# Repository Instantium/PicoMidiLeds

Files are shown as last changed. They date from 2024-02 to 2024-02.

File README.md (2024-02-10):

# PicoMidiLeds

Use a Pi Pico to control RGB Led strips via midi signals. 

## Features
- Control up to 6 Led channels with midi signals
- Daisy chain controllers together
- Note velocity controls Led brightness
- Dim all Led channels with the modulation control command
- Ignores note_off events so that the leds stay on when the midi track ends
- Set a default value for each channel
- Midi-in and midi-out via DIN-5
- Midi-in via usb
- Optocoupler protects pico from midi-in

## Rationale 

The band [Fliegende Haie](https://fliegendehaie.com) approached me to find a way to control multiple Led strips in accordance to their music tracks on stage.

They already had DIYed stage lighting consisting of two sharks in clouds. 
Each shark consists of two RGB-LED strips (one for the shark and one for the cloud).

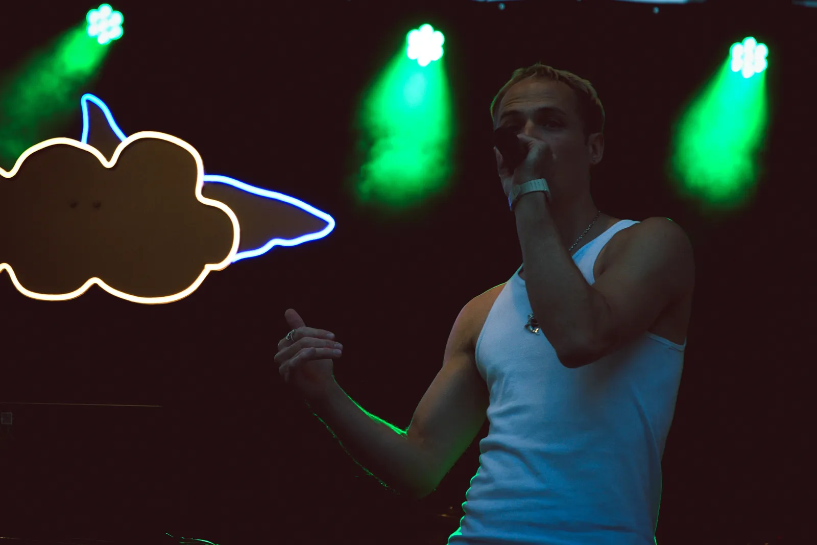
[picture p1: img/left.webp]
[](https://fliegendehaie.com/uber)
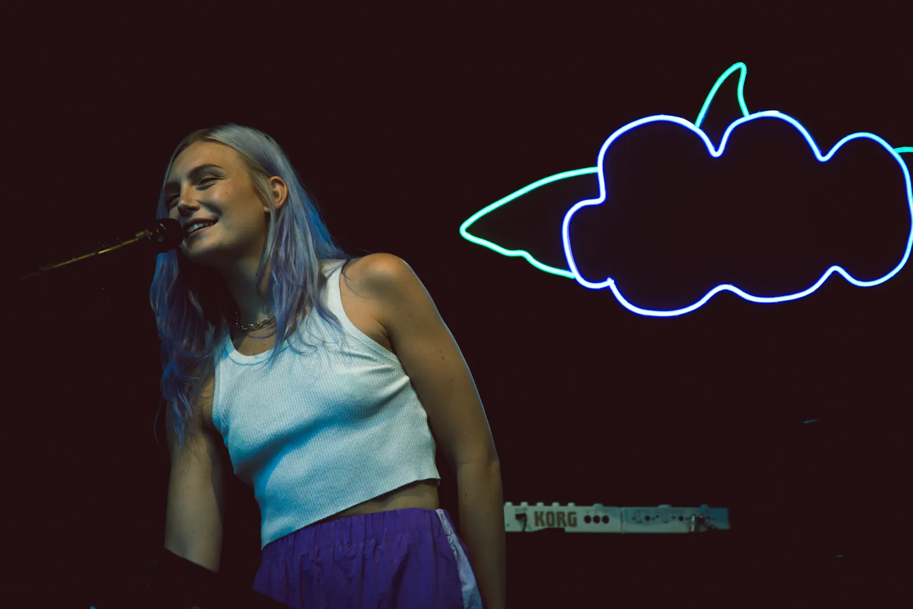
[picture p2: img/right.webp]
[](https://fliegendehaie.com/uber)

Using existing stage lighting solutions (like [DMX](https://en.wikipedia.org/wiki/DMX512)) would mean a huge cost and steep learning curve. 
Since the band members already knew how to write midi tracks and had the hardware, it was the obvious choice to control the lighting via midi commands.



## Setup

### Firmware

- Install [Adafruit cricuit python](https://learn.adafruit.com/getting-started-with-raspberry-pi-pico-circuitpython/circuitpython) on the pico
- Download [library bundle](https://circuitpython.org/libraries)
- Copy adafruit midi to the Pico
- Rename PicoMidi.py to code.py
- Copy config.py and code.py to the Pico

### Config

Configurations should be made in the config.py file. See comments for explanation.

### PCB 

You can use the [Kicad project](board/pico-midi-leds/pico-midi-leds.kicad_pro) or just send the production files (board/pico-midi-leds/production/pico-midi-leds_2024-02-07_08-46-34) to a PCB-Manufacturerer. Or approach me since I have some populated boards left over.

Version 1 with bodgewires (already fixed):

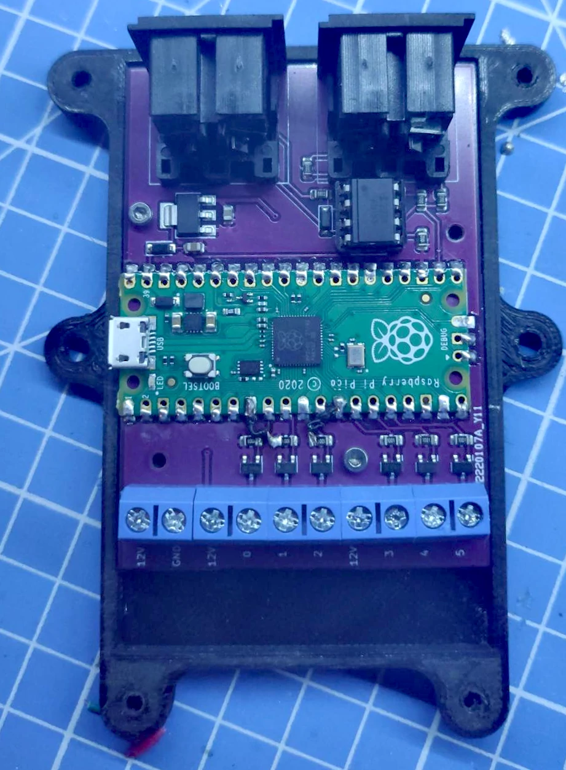
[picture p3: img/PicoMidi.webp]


### Enclosure

I added the stl files for an enclosure [Top](enclosure/PicoMidi%20-%20Lid.stl) and [Bottom](enclosure/PicoMidi%20-%20Bottom.stl) that can be used as enclosure.

## Todos
- Specify midi channel
- Enable midi out from usb (reqiures hardware change)
- Make ignoring note_off configurable

## Thanks

Thanks to [Fliegende Haie](https://fliegendehaie.com) for agreeing to make this project open source.

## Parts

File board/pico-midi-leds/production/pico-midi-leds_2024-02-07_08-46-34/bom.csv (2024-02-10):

Designator | Footprint | Quantity | Value | LCSC Part #
C1 | 0805 | 1 | 10u
C2 | 0805 | 1 | 22u
D1 | D_SOD-123 | 1 | 1N4148
D2 | D_SOD-123 | 1 | D_Schottky
H1, H2, H3, H4 | MountingHole_2.2mm_M2 | 4 | MountingHole
J1, J2 | TerminalBlock_bornier-4_P5.08mm | 2 | Screw_Terminal_01x04
J3 | TerminalBlock_bornier-2_P5.08mm | 1 | Screw_Terminal_01x02
J4, J5 | din-504-M10 | 2 | DIN-5_180degree | C2939344
Q1, Q2, Q3, Q4, Q5, Q6 | SOT-23 | 6 | IRLZ44N
R1, R4, R5 | 0805 | 3 | 220R
R10, R11, R6, R7, R8, R9 | 0805 | 6 | 1k
R2 | 0805 | 1 | 470R
R3 | 0805 | 1 | 10kR
U1 | RPi_Pico_SMD_TH | 1 | Pico
U2 | DIP-8_W7.62mm | 1 | 6N138
U3 | SOT-223-3_TabPin2 | 1 | AMS1117-5.0

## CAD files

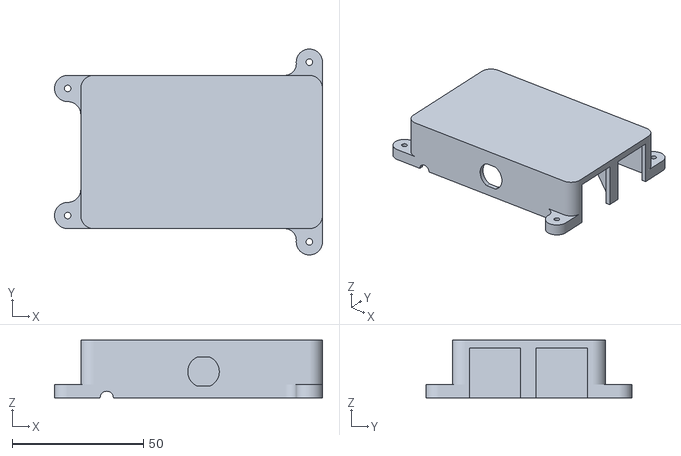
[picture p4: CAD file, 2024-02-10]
enclosure/PicoMidi - Lid.stl
102.0 x 78.3 x 21.9

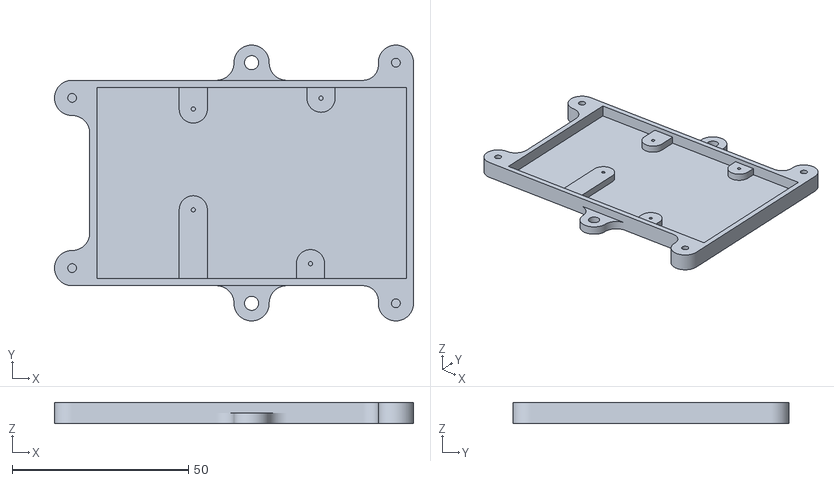
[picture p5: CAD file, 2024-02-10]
enclosure/PicoMidi - Bottom.stl
102.0 x 78.3 x 6.08

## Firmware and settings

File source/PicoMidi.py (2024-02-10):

import board
import time
import pwmio
import busio
import adafruit_midi
import usb_midi
import config
from adafruit_midi.note_on import NoteOn
from adafruit_midi.control_change import ControlChange

CC_MODULATION = 1

# Midi output settings
midi_channel = 1  # Target midi channel to write to
usb_midi = adafruit_midi.MIDI(midi_in=usb_midi.ports[0], debug=True)
# UART Midi device on pin 6
uart = busio.UART(tx=board.GP16, rx=board.GP17, baudrate=31250, timeout=0.001)
uart_midi = adafruit_midi.MIDI(midi_out=uart, midi_in=uart, debug=True)

led_pins = [
    board.GP6,
    board.GP7,
    board.GP8,
    board.GP10,
    board.GP11,
    board.GP12,
]

last_message_at = 0
is_default_showing = True
global_brightness_factor = 1


def processMidiMessage(message):
    global last_message_at
    global is_default_showing
    global global_brightness_factor

    if isinstance(message, NoteOn):
        last_message_at = time.time()

        if message.note == config.note_display_default:
            displayDefault()
            return

        if message.note == config.note_clear_all:
            for i in range(len(led_colors)):
                led_colors[i] = 0
            return

        if is_default_showing:
            for led in leds:
                led.duty_cycle = 0
            is_default_showing = False

        try:
            led_index = config.note_mapping.index(message.note)

            print("index:")
            print(led_index)
            print(message.velocity)

            led_colors[led_index] = message.velocity

        except ValueError:
            print("not interested in note")

    elif isinstance(message, ControlChange) and message.control == CC_MODULATION:
        global_brightness_factor = abs(message.value) % 128 / 127


def update_leds():
    for led, color in zip(leds, led_colors):
        color_factor = min(color / 127, 1)

        led.duty_cycle = int(
            pow(65535, color_factor * global_brightness_factor))


def displayDefault():
    global is_default_showing
    global led_colors
    led_colors = [color for color in config.default_colors]
    is_default_showing = True


# Setup
displayDefault()
leds = [pwmio.PWMOut(lp, frequency=1000, duty_cycle=0) for lp in led_pins]
print("Init done")

# main loop
while True:
    in_message = usb_midi.receive()
    if in_message is not None:
        print("Received USB message")
        print(in_message)

        # uart_midi.send(in_message)

        # BEWARE: channel is always 0
        processMidiMessage(in_message)

    in_message = uart_midi.receive()
    if in_message is not None:
        print("Received uart message")
        print(in_message)
        # BEWARE: channel is always 0
        processMidiMessage(in_message)

    if config.timeout > 0 and time.time() - last_message_at > config.timeout:
        displayDefault()

    update_leds()

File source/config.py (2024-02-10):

# The Default Colors that are shown when the device is powered on or when note_display_default was played
# Values from 0-127 inclusive
default_colors = [
    50,     # Red
    127,    # Green
    50,     # Blue
    0,      # Red
    90,     # Green
    127     # Blue
]

# Displays the default color (Does not reset the global brightness changed by pitch bend)
note_display_default = 15
# Sets all LEDS to 0 (Does not reset the global brightness changed by pitch bend)
note_clear_all = 13

# When no message was received for timeout in seconds the default colors will be shown
# A value of -1 equals no timeout
timeout = -1

# Midi notes that correspong to the Led-channels
note_mapping = [
    12,
    14,
    16,
    17,
    19,
    21
]
